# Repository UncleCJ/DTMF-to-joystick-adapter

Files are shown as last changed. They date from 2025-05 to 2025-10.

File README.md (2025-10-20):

# Arduino Telephone DTMF to Amiga 9-pin joystick adapter for TV classic Hugo game

Note for now: I am very happy and pleased I managed to pull this project off - but _not_ proud of various details in how it is done. Reproduce at your own risk, there is magic smoke ahead...

## Overview

## Plain old telephone service, POTS

An early decision was whether to butcher the telephone, wiring straight onto the keypad, or leaving it intact, actually driving something resembling a telephone circuit and actually decoding the tone (Dual-tone multi-frequency, DTMF) signalling.  
Turns out, the keypad ribbon cable interface looked simple enough, but since the telephone actually decodes its key matrix and encodes DTMF from it (it’s what the keypad is for, after all), I thought it the cleaner path to go, no messing with wiring through the telephone casing.  
There are many ways to revive ([Publicly offered telephone service or Plain old telephone service, POTS](https://en.wikipedia.org/wiki/Plain_old_telephone_service)) telephones and since maintaining some hundred years of backwards compatibility (except for pulse vs DTMF dialling), they’re robust as heck. Realising I didn’t have much telephone equipment available (no jacks or clips and merely a couple meters of torn out wire), it had all been quietly discarded over the years, I also didn’t opt for a full [(IP) telephony system](https://www.amazon.se/dp/B08RB1B1F8), when, turns out you can drive phones by just placing them in series with a 9V battery!  
It was quite the joy to have a (single) live telephone and for instance dialling the phone number of my birth home.  
Here came also the first challenge of how to get a reasonable audio signal out of our telephone circuit (microphone with amplifier creating a ripple around 9V which a speaker can make into sound)? Most projects described online after all use phones to communicate with some kind of phone, or jump straight to DTMF decoding. After reading this excellent article regarding an [audio tap](https://www.ranecommercial.com/legacy/note150.html), and since we didn’t need to act compliant with any proper telephone system, all it took was a crude RC high pass filter, and I could read the millivolts weak audio over the resistor.  

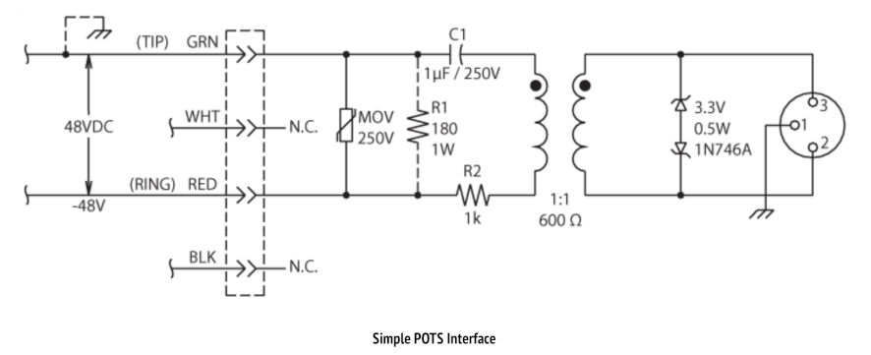
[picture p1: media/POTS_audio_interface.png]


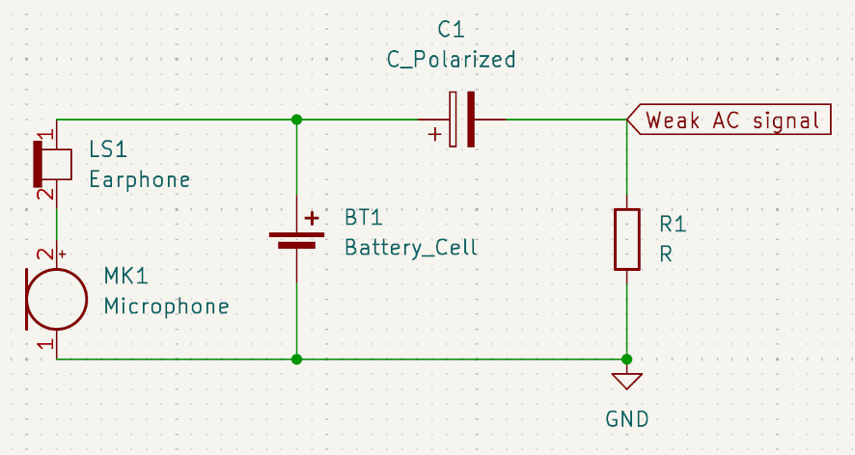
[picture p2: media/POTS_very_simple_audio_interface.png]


I probably could have used the opportunity to learn how to use [transistors or the opamp chips](https://www.instructables.com/Audio-Amplifier-With-the-LM386) I keep around, but felt like finally trying out the cheapo [LM386 amplifier moduless](https://www.aliexpress.com/item/1005004606022112.html) which also had gathered dust until now. It worked! A clear, manageable signal!  
Se [here](media/DTMF_FFT.mp4) for a clip showing that signal on my oscilloscope. It was yet another achievement to for the first time understand [the oscilloscope settings to show the FFT](https://www.bruksanvisni.ng/rigol/ds1104z-plus/bruksanvisning?p=120) - here centered on 1 kHz with 200 Hz/division, below 5 ms of the 2.4 V AC waveform. Note how "1" appears with the lowest (697 Hz) of the rows group, as well as the lowest (1209 Hz) of the columns group, whereas "3" would be the lowest of the rows and the highest of the three standard columns (1477 Hz). Thus "3" has the peaks widest apart, but "*" has them most narrow (last row, 941 Hz, first column, again 1209 Hz).  

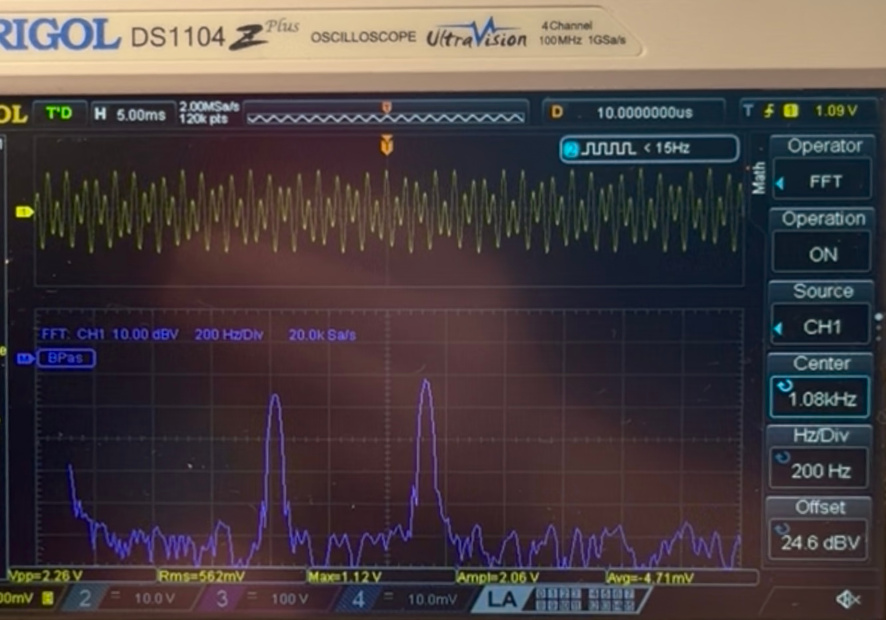
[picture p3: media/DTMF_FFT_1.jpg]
waveform and FFT representing the "1" key


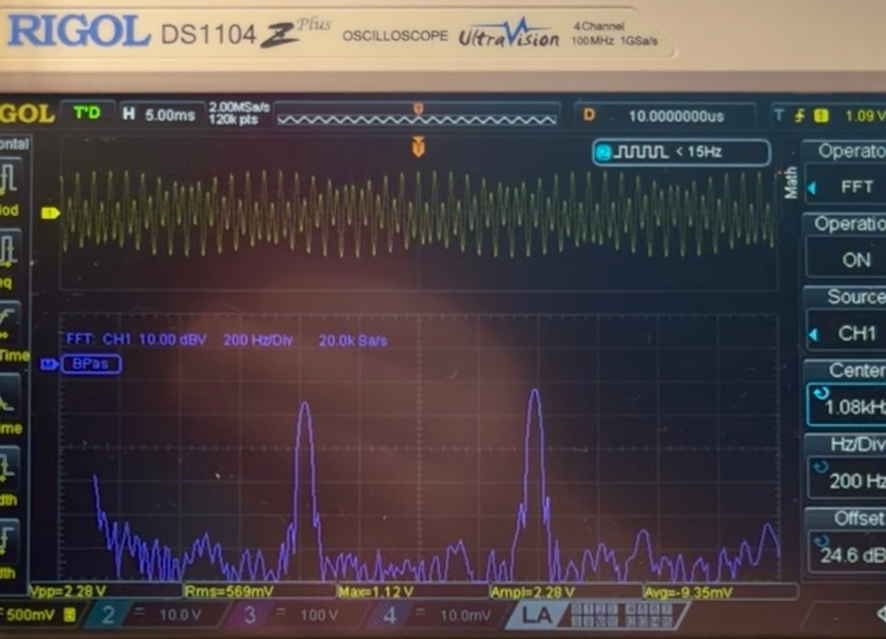
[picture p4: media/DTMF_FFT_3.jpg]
waveform and FFT representing the "3" key


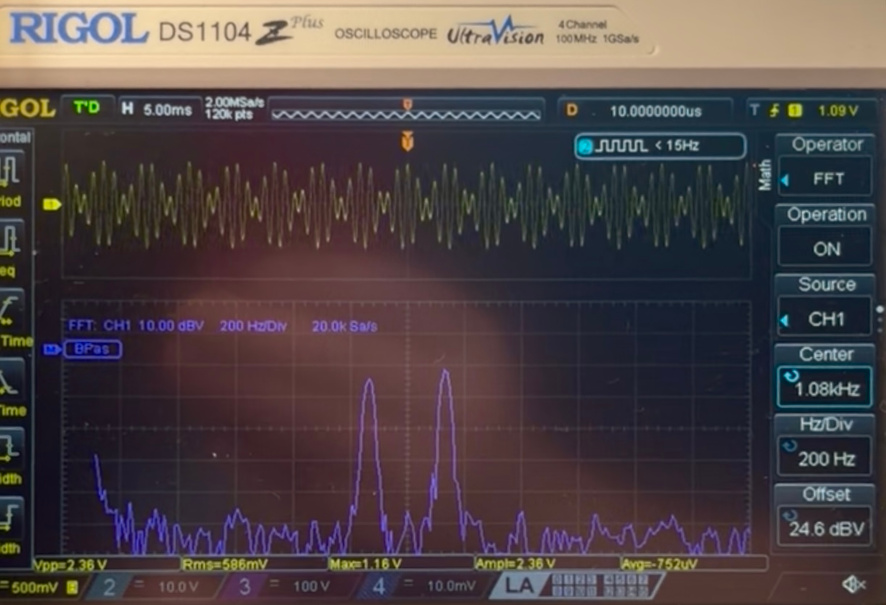
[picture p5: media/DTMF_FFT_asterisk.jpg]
waveform and FFT representing the "\*" key


## Dual-tone multi-frequency, DTMF 

So, before telephony went packed switched (IP), signalling (here equivalent to dialling) was done in circuit. Initially as pulse sequences (rotate a spring loaded wheel to create a certain number of pulses) and later as [Dual-tone multi-frequency, DTMF](https://en.wikipedia.org/wiki/DTMF_signaling). Two specific, plain sinusoidal tones as a kind of chord represent the column and row (verify and perhaps swap these around later) of the standardised keypad which has been pressed.  
Generate DTMF tones in your browser [here](https://onlinetonegenerator.com/dtmf.html).

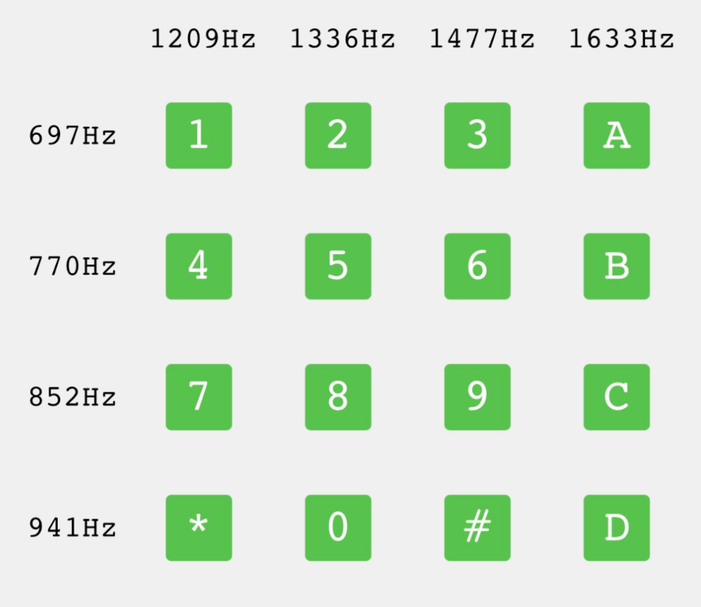
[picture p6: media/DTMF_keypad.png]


Most projects describe using [a (fairly cheap) decoder module](https://www.aliexpress.com/item/1005006831612752.html) to convert these tones into… digital pins representing the columns and rows. Being really neat and proper, the decoder even [comply with some DTMF standards](https://www.alldatasheet.com/html-pdf/77085/MITEL/MT8870/125/1/MT8870.html) regarding detection timing and output two additional pins signifying when there really, for sure was a keypress detected.  

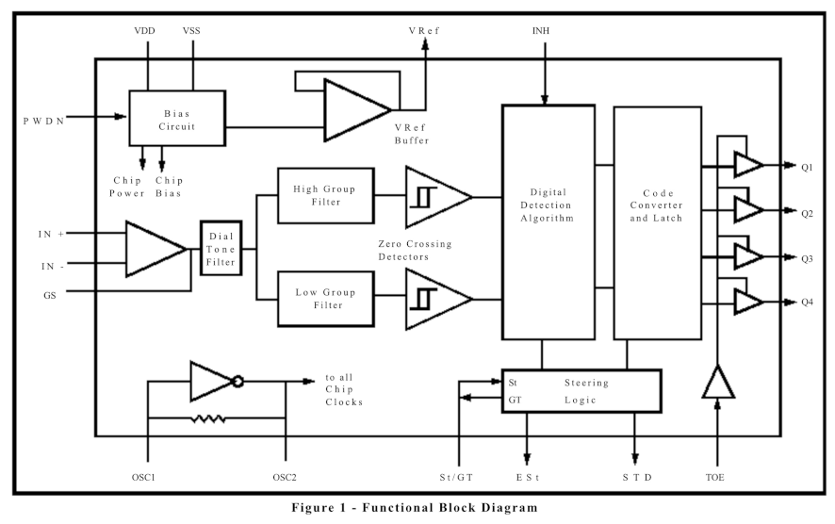
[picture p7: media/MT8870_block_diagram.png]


Not that I required a standards-compliant decoder module, but as an exercise I sketched a circuit of logic gates which might have transcoded the key matrix straight to joystick output.  

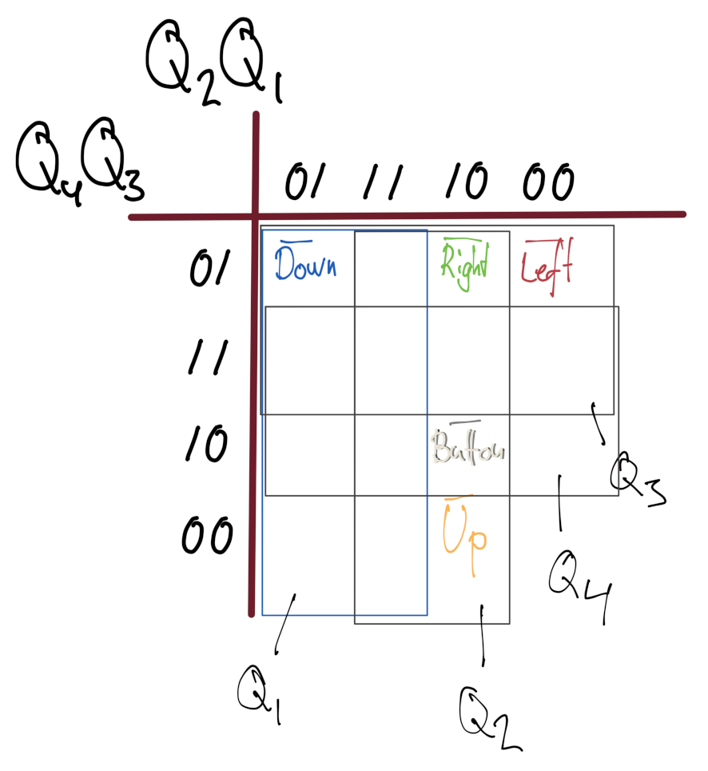
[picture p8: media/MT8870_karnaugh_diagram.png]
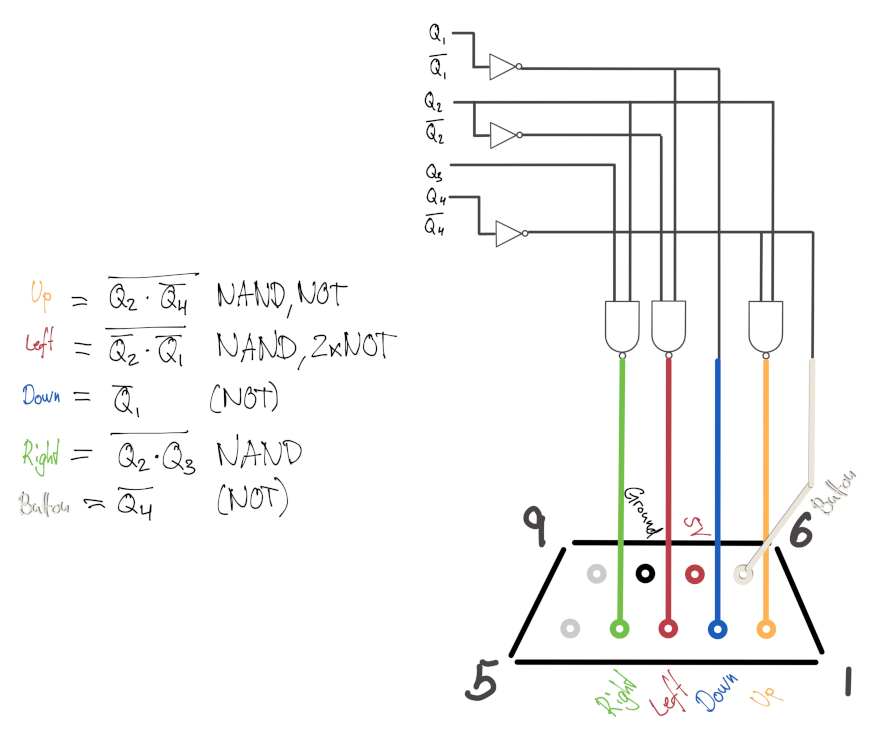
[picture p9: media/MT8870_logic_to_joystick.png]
 

However, being a masoch… I mean perfectionist, and also since botching my AliExpress shopping cart, hardware decoders wouldn’t arrive on time, so I might as well implement my own in software.   

## DTMF decoding and the Discrete Fourier Transform

According to its block diagram above the DTMF decoding module separate the rows and columns groups of tones and thus can determine frequencies by counting zero-crossings, which doesn't work when tones (and noise) are all mixed together. We will need some kind of discrete Fourier transform, DFT.  
If you have read this far, odds are that you are familiar with the Fast Fourier Transform, FFT. If you're not, let's just say it is a particular way to calculate the full Discrete Fourier Transform, DFT, for some *window* of N samples taken at some *sampling frequency*. Transform is a generic, almost magical mathematical term for changing your data into some different perspective without losing any information, at least within the given criteria. The perspectives applicable to DFT is that given data in the *time domain* you transform it into the *frequency (and phase) domain*, commonly known as a *spectrum* (yes, you probably understood that right, it is comparable to some mix of light, shifting to describing it as which colors/wave lengths/frequencies the light is made up of).
Common for any method of DFT is that the spectrum will cover *half the sampling frequency (f<sub>S</sub>)* (in practice that one must sample any tone at least twice per wavelength for it to be distinguishable). This maximum frequency threshold of what will be represented in the DFT is called the Nyquist frequency. Frequency content above the Nyquist frequency (unless removed by low pass filtering) will be folded, or aliased about the Nyquist frequency, distorting the transformed spectrum (let's not dig deeper for now, but for instance frequencies close to the sampling frequency would be falsely represented as peaks of low frequency in the spectrum).
A spectrum calculated from a longer window of samples will have greater frequency resolution or more "buckets", each f<sub>S</sub>/N wide. Thus there is always a compromise to be made regarding sampling frequency and window length - sample as often as needed but not much more, and for long enough to distinguish the frequencies needed, but no longer which could both waste memory (unless one can process and then discard each sample, as will be described) and cause latency - unwanted delay in getting the spectrum once the signal has been sampled.
To establish some numbers, note that the highest DTMF tone we will care about, the third column is 1477 Hz, so we need at least a sampling frequency of 2954 Hz. The tones are spaced in a particular way to avoid overtones colliding, but the smallest spacing is 73 Hz, requiring at least N = 40 samples or 14 ms sampling window. In practice we will use a bit of margin on that though.  
When you have little use of the entire spectrum ... 

https://en.wikipedia.org/wiki/Nyquist_frequency

## Goertzel tone detection on arduino

I have a collection of both microcontrollers, single-board computers and various other devices. I considered the Raspberry Pi Pico, or Teensy, good options should I need to perform full FFT. 

Arduino Nano Every / ATMega4809 

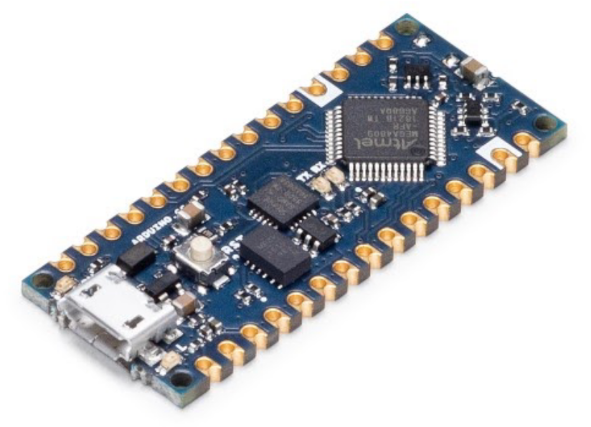
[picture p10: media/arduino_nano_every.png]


https://docs.arduino.cc/hardware/nano-every/

https://content.arduino.cc/assets/Nano-Every_processor-48-pin-Data-Sheet-megaAVR-0-series-DS40002016B.pdf

5kHz sampling

Goertzel

Realtime

https://en.wikipedia.org/wiki/Goertzel_algorithm

https://www.hackster.io/MM_Shoaib/dtmf-decoder-using-only-arduino-872502

https://github.com/AI5GW/Goertzel

https://projecthub.arduino.cc/RoyB/goertzel-algorithm-b39509

## Amiga joystick 

DTMF to joystick



## Circuit

## Stripboard and RetroPie emulator

Frustratingly, the system just barely worked with the Amiga hardware in the first cruise. Main issues were the instability of components on a breadboard, my failed ambition to passively mix the game and DTMF audio and - the noise from the event stage completely drowning out DTMF detection, constantly causing erratic joystick events!

Despite these issues (and the personal associated crippling stress), Hugo nostalgia and the potential of playing it on a phone keypad excited many visitors. Geeks.se (Moderskeppet creators) suggested a "foolproof build" for a subsequent cruise, and so I did not after all let the build perish in fire (nor in the Baltic Sea) but brought it out again to see what could be achieved.

Another pursuit of mine is emulators, including mitigating inefficiencies enough for them to run on otherwise limited resources. The system ought to become more foolproof replacing the, in itself fairly complex, Amiga 500/pistorm/rgb2hdmi hardware with a Raspberry Pi 3 running [RetroPie](https://retropie.org.uk). Amiga emulation may not be as common as other platforms - input configuration is complicated by both joysticks, mouse and keyboard, as well as the requirement to sort out the various BIOS ("kickstart") requirements and "rom" formats (I prefer [WHDLoad](https://docs.libretro.com/library/puae/#whdload_1)). This sorted, Amiga emulation and the Hugo game runs ok using [libretro puae 2021](https://docs.libretro.com/library/puae), notably requiring frameskip to be enabled for the mountain level (probably due to its pseudo-3D scrolling). Noting down the "runcommand" I could add the emulator and Hugo to [retropie/configs/all/autostart.sh](https://retropie.org.uk/docs/FAQ/#how-do-i-boot-to-the-desktop-or-kodi). Finally the [overlay file system](https://www.raspberrypi.com/documentation/computers/configuration.html#overlay-file-system) is enabled to protect the Raspberry Pi from crashes or unintended changes.

To improve the electrical situation I wanted to try [stripboard (veroboard)](https://en.wikipedia.org/wiki/Stripboard) or [perfboard](https://en.wikipedia.org/wiki/Perfboard)...

https://en.wikipedia.org/wiki/18650_battery

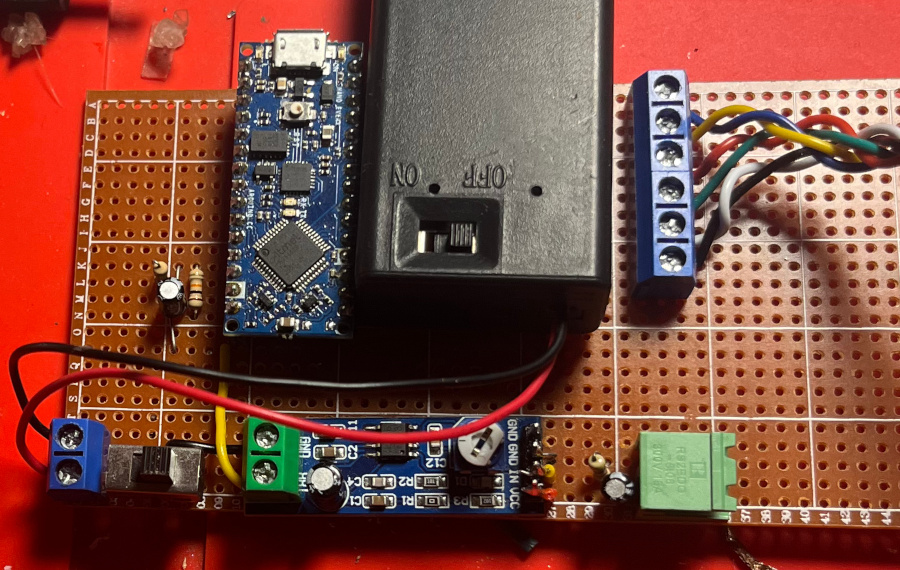
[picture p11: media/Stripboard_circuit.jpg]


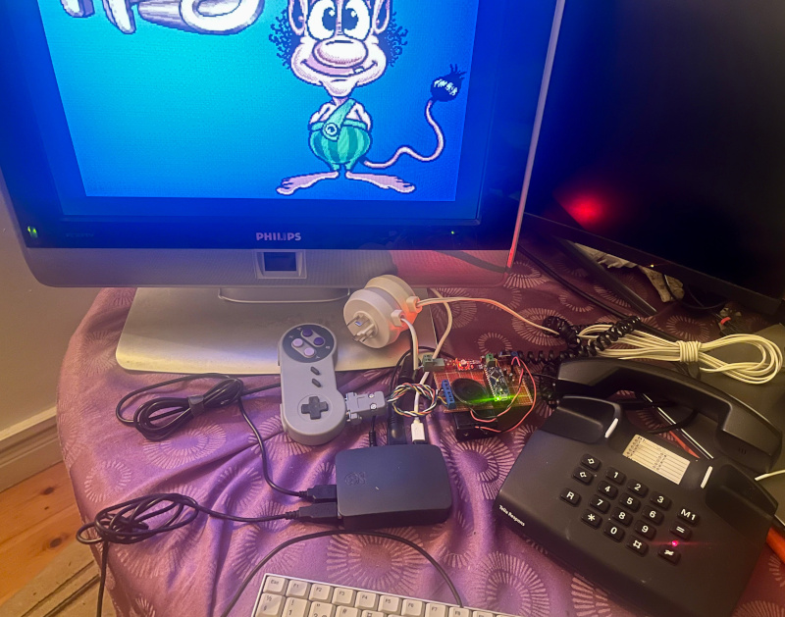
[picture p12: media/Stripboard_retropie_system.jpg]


## Todo

* raspberry port, self contained emulator
* Hugo variants
* Cleanup, arduino library, platformio 

## Changelog

* DTMF fft 
* DTMF decoding and 5 pins
* Amiga controller test
* Audio mixing
* Telephone wire
* Cruise! Wiring
* Success!
* 2025-10: Moderskeppet 4 cruise - Stripboard circuit and RetroPie emulator

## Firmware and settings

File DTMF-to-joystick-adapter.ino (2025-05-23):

// atmega4809_adc.ino
void ADC0_init(void);
void ADC0_start(void);
bool ADC0_done(void);
uint16_t ADC0_read(void);
void ADC0_stop(void);

class Goertzel {
  public:
  Goertzel();
  Goertzel(float, float, int);
  void sample(void);
  float detect(void);
  void ProcessSample(uint16_t);

  private:  
  float sin_o;
  float cos_o;
  float C;
  float Q1;
  float Q2;
  void GetComplexResult(float*, float*);
  void Reset(void);
};

class HugoJoystick {
  public:
  HugoJoystick(int, int, int, int, int);
  void update(char);

  private:
  void release(int);
  void activate(int);
  void button_actuate(void (HugoJoystick::*)(int), char);
  void button_release(char);
  void button_activate(char);
  int UP, DOWN, LEFT, RIGHT, FIRE;
  char active, recent;
};


// const int n = 481;  // 480 / 4.8 kHz = 100 ms
const int n = 120;  // ~25 ms, perhaps enough for 697 Hz (the longest period/lowest frequency)

Goertzel goertzels[7];

HugoJoystick joystick(9, 11, 5, 7, 3);


void setup() {
  // Columns 1209 (32) 1336 (35) 1477 (39) (1633)
  // Rows 697 (18, 676.125) 770 (20) 852 (22) 941 (25)
  Serial.begin(115200);
  ADC0_init();

  goertzels[0] = Goertzel(4808.0, 697.0, n);
  goertzels[1] = Goertzel(4808.0, 770.0, n);
  goertzels[2] = Goertzel(4808.0, 852.0, n);
  goertzels[3] = Goertzel(4808.0, 941.0, n);
  goertzels[4] = Goertzel(4808.0, 1209.0, n);
  goertzels[5] = Goertzel(4808.0, 1336.0, n);
  goertzels[6] = Goertzel(4808.0, 1477.0, n);
}

void loop() {
  uint16_t sample;
  float magnitudes[7];  // We are working with 7 DTMF tones, four rows + the three first columns

  ADC0_start();
  for (int i=0; i < n; i++) {
    while (1) {
      if (ADC0_done()) {
        sample = ADC0_read();
        break;
      }
    }

    for (int j=0; j < 7; j++) {
      goertzels[j].ProcessSample(sample);
    }
  }
  ADC0_stop();

  for (int j=0; j < 7; j++) {
    magnitudes[j] = goertzels[j].detect();
  }

  char decoded = DTMF_decode_magnitudes(magnitudes);
  Serial.println(decoded);
  joystick.update(decoded);

  // delay(2000);
}

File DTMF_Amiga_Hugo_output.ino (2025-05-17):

void HugoJoystick::release(int pin) {
  pinMode(pin, INPUT);
}

void HugoJoystick::activate(int pin) {
  pinMode(pin, OUTPUT);
  digitalWrite(pin, LOW);
}

void HugoJoystick::button_actuate(void (HugoJoystick::*actuator)(int), char button) {
  switch (button) {
    case '4':
      (this->*actuator)(LEFT);
      break;
    case '5':
      (this->*actuator)(UP);
      break;
    case '6':
      (this->*actuator)(RIGHT);
      break;
    case '9':
      (this->*actuator)(RIGHT);
      (this->*actuator)(UP);
      break;
    case '8':
      (this->*actuator)(DOWN);
      break;
    case '0':
      (this->*actuator)(FIRE);
      break;
    default:
      break;
  }

}

void HugoJoystick::button_release(char button) {
  button_actuate(&HugoJoystick::release, button);
}


void HugoJoystick::button_activate(char button) {
  button_actuate(&HugoJoystick::activate, button);
}

HugoJoystick::HugoJoystick(int up, int down, int right, int left, int fire)
    : UP(up), 
      DOWN(down), 
      LEFT(left), 
      RIGHT(right),
      FIRE(fire) {   
  int pins[] = {UP, DOWN, LEFT, RIGHT, FIRE};
  for (int pin : pins) {
    release(pin);
  }
  active = ' ';
  recent = ' ';
}

void HugoJoystick::update(char current) {
  if (current != '4'
        && current != '5'
        && current != '6' 
        && current != '8'
        && current != '9'
        && current != '0') { // current is not a valid joystick input
    if (active == ' ' || recent != ' ') {
      recent = ' ';
      return;
    }
    else { // active != ' ' && recent == ' '
      button_release(active);
      active = ' ';
      return;
    }
  }
  else { // current is a valid joystick input
    if (active == current
        || recent != current) {
      recent = current;
      return;
    }
    else { // active != current && recent == current
      button_release(active);
      button_activate(current);
      active = current;
      return;
    }
  }   
}

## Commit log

2025-05-23 squash! WIP: Expand README.md with project story
    Adding (rudimentary) kicad schematic for illustrations
    [DTMF-to-joystick-adapter.kicad_pcb, DTMF-to-joystick-adapter.kicad_sch]
2026-10-15 Add the Goertzel algorithm implemented in Python (WIP)
    Tidied goertzel detector, works pretty well!
    This setup:
    ```
    dtmf_frequencies = (697.0, 770.0, 852.0, 941.0, 1209.0, 1336.0, 1477.0)
    dtmf_detectors = tuple(
    GoertzelDetector(f_sampling, f_target, samples_per_window)
    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
